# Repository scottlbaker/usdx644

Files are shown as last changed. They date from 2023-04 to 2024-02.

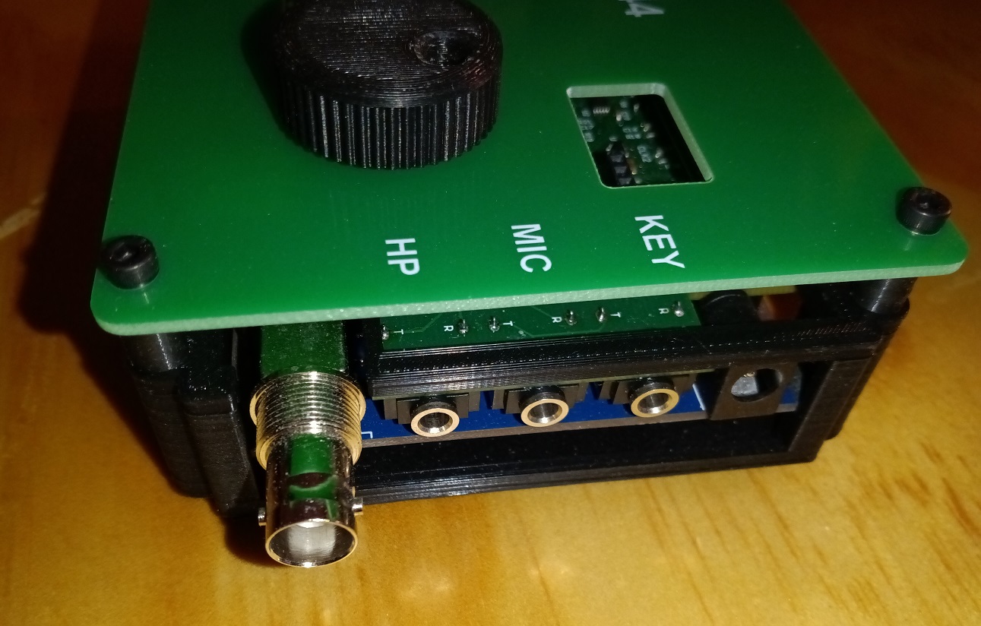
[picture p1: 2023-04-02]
hardware/pics/side_view.jpg

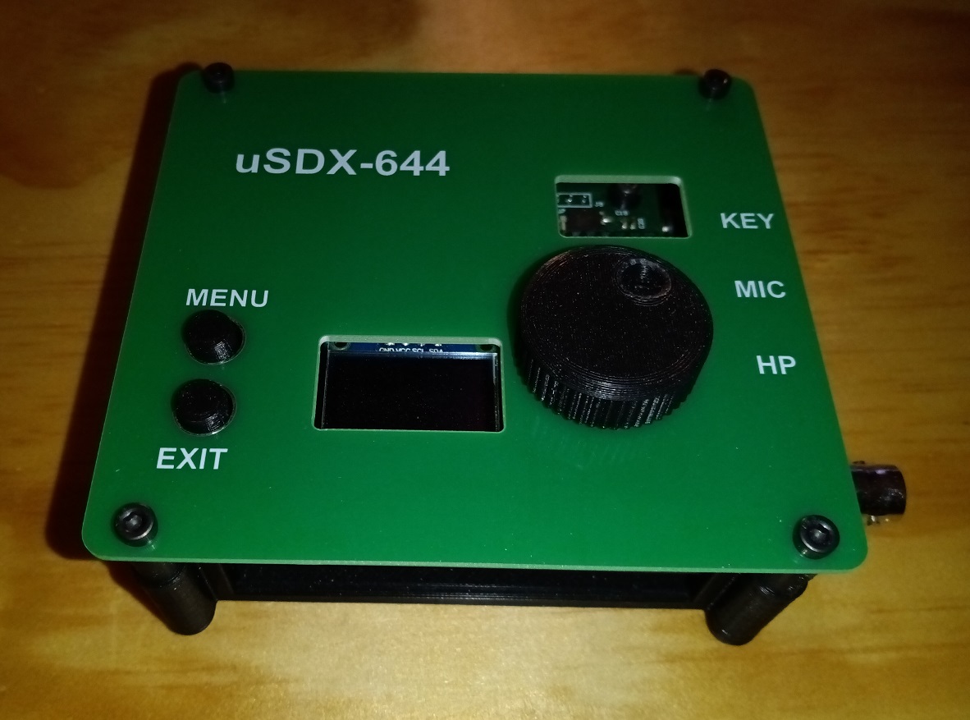
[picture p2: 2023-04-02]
hardware/pics/top_view.jpg

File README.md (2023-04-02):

## Summary

This SDR radio project was inspired by the uSDX project by Guido PE1NNZ.
The processor used is the Atmega644 processor which has more RAM and Flash memory
than the Atmega328 used in the uSDX project.

## Description

A single board SDR radio that is electrically and mechanically compaible with
an 8-band Chinese uSDX clone RF board.

## Contributors

* Scott L Baker

## License

See the **LICENSE** file in this repository

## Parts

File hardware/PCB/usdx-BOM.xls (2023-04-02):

Designator | Comment | Footprint | Quantity | Part Number
C1,C5,C6,C10,C11,C14,C15,C17,C19,C22,C25,C26,C27,C28,C29 | .1uF | 3-0603 | 15 | C113803
C2,C3,C7,C8 | .47uF | 3-0603 | 4 | C1623
C4,C9 | 1000pF | 3-0603 | 2 | C77026
C12,C13,C20,C21,C30,C31,C33 | 10uF | 3-0603 | 7 | C344022
C16,C23,C24 | .01uF | 3-0603 | 3 | C76710
C18,C32 | 1uF | 3-0603 | 2 | C5673
D1 | LED1 | 3-0603 | 1 | C72044
L1 | 100uH | 6-0805 | 1 | C223258
L2 | 3.3uH | 8-1008 | 1 | C250218
Q1 | CJ2302 | SOT23 | 1 | C8548
R1,R2,R3,R4,R17,R19,R30 | 1k | 3-0603 | 7 | C14676
R5,R6,R12,R13,R31 | 100 | 3-0603 | 5 | C22775
R7,R8,R9,R11,R14,R16,R20,R21,R24,R25,R26,R27,R28,R29,R32 | 10k | 3-0603 | 15 | C167144
R10,R15 | 82k | 3-0603 | 2 | C23254
R18 | 50 | 3-0603 | 1 | C23185
R22 | 4.7k | 3-0603 | 1 | C99782
R23 | 3.3k | 3-0603 | 1 | C22978
U2 | Si5351A | MSOP-10 | 1 | C1509083
U3 | LM4562 | SOIC-8 | 1 | C57367
U4 | FST3253 | TSSOP-16 | 1 | C424399
U5 | TLV702 | SOT-23-5 | 1 | C84119
U6,U8 | 74LVC1G08 | SOT23-5 | 2 | C434068
U7 | LM117-DPAK | TO252-3 | 1 | C129951

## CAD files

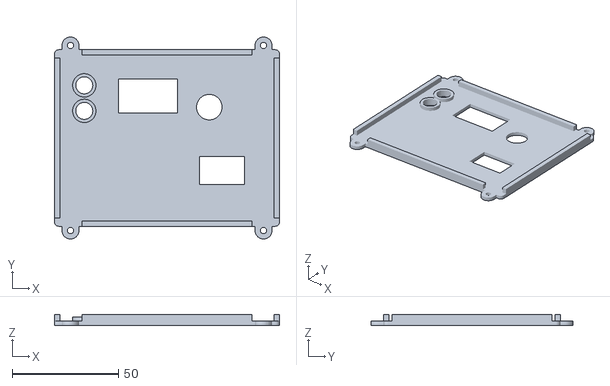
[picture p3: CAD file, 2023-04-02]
hardware/case/top.stl
105.8 x 95.0 x 5.00

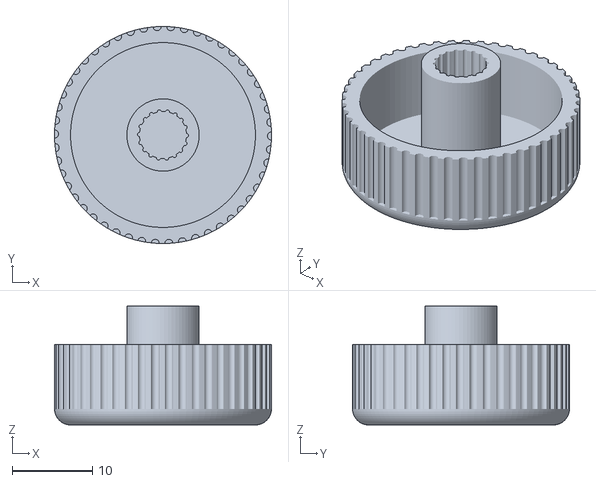
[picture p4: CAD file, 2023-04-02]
hardware/case/knob.stl
27.0 x 27.0 x 14.8

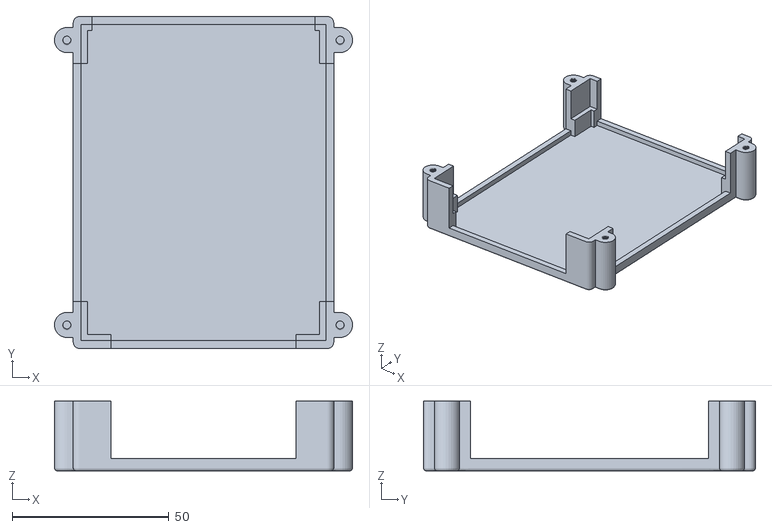
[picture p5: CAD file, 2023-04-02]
hardware/case/base.stl
95.0 x 105.8 x 22.2

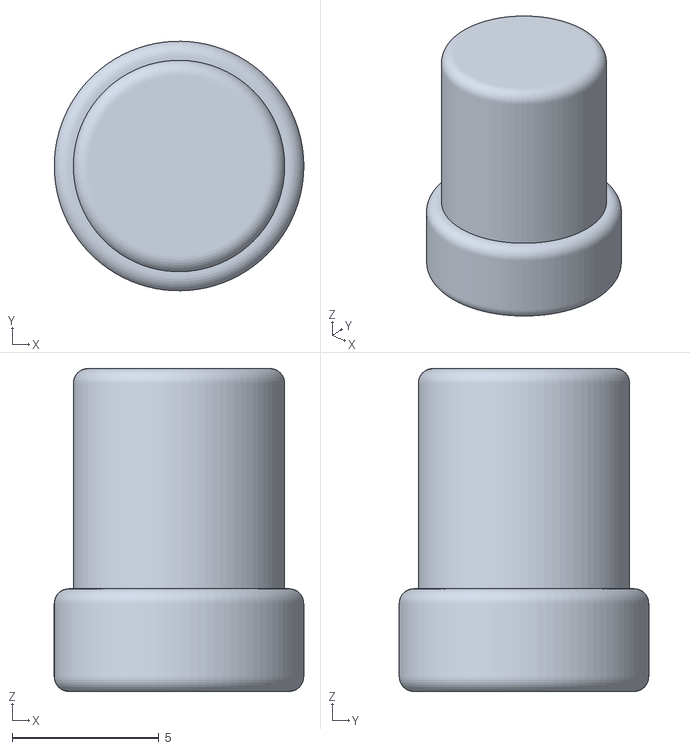
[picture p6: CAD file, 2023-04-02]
hardware/case/button.stl
8.50 x 8.50 x 11.0

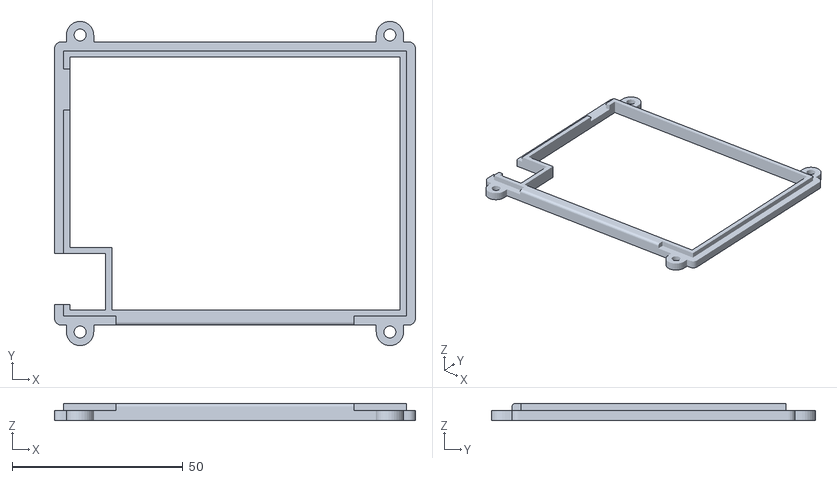
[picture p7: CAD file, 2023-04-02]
hardware/case/gasket.stl
105.8 x 95.0 x 5.00

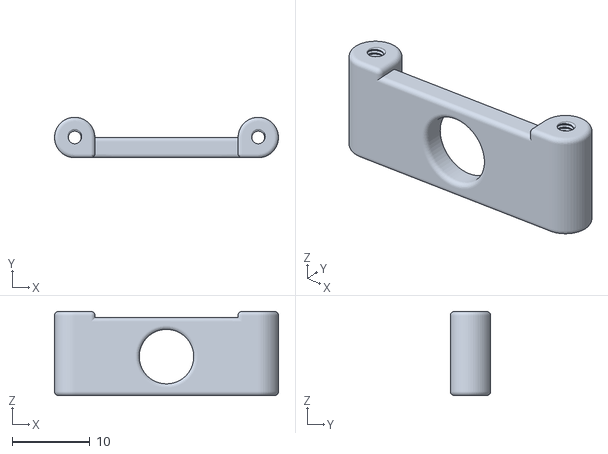
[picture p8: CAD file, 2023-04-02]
hardware/case/lcd.stl
28.8 x 5.20 x 10.8

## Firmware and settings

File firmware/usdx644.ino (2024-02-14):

// ============================================================================
//
// usdx644.ino :: An SSB/CW capable QRP transceiver
//
// (c) Scott Baker KJ7NLA
//
// This project was inspired by the uSDX project by Guido PE1NNZ
// which used the Atmega328 processor. This project uses the Atmega644
// processor which has more RAM and Flash memory
//
// Libraries
// ---------
// wire.h         - Arduino I2C lib
// wdt.h          - Arduino watchdog timer lib
// EEPROMex.h     - eeprom read/write lib
// font.h         - an OLED font that I created
//
// Arduino IDE settings
// --------------------
// board: Atmega644 (MightyCore)
// clock: external 16MHz
// BOD: BOD 2.7V
// eeprom: eeprom retained
// variant: 644P 644PA
// pinout: standard
// bootloader: no bootloader
// programmer: AVRISP mkII (MightyCore)
//
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
// ============================================================================

#define VERSION   "1.00X"               // firmware version
#define DATE      "Jan 14 2024"         // firmware release date

// Arduino Pins

#define QSDQ      PIN_PA0     // Q
#define QSDI      PIN_PA1     // I
#define MIC       PIN_PA2     // microphone
#define XP3       PIN_PA3     // extra pin (not used)
#define XP2       PIN_PA4     // extra pin (not used)
#define VBAT      PIN_PA5     // battery voltage
#define VFWD      PIN_PA6     // SWR fwd voltage
#define VREV      PIN_PA7     // SWR rev voltage

#define BLINKY    PIN_PB0     // diag LED
#define XP4       PIN_PB1     // extra pin (not used)
#define SDA0      PIN_PB2     // I2C bus #0 (si5351)
#define SCL0      PIN_PB3     // I2C bus #0 (si5351)
#define RXEN      PIN_PB4     // Receive control
#define MOSI      PIN_PB5     // SPI programming pin
#define MISO      PIN_PB6     // SPI programming pin
#define SCK       PIN_PB7     // SPI programming pin

#define SCL1      PIN_PC0     // I2C bus #1 (OLED)
#define SDA1      PIN_PC1     // I2C bus #1 (OLED)
#define UI2       PIN_PC2     // user button (exit)
#define UI1       PIN_PC3     // user button (menu)
#define UI3       PIN_PC4     // user button (encoder)
#define ROTA      PIN_PC5     // rotary encoder A
#define ROTB      PIN_PC6     // rotary encoder B
#define XPTT      PIN_PC7     // external amp control

#define RXD       PIN_PD0     // serial port Rx
#define TXD       PIN_PD1     // serial port Tx
#define CSS       PIN_PD2     // SPI select
#define DIT       PIN_PD3     // dit/ptt
#define PTT       PIN_PD3     // dit/ptt
#define TXPWM     PIN_PD4     // transmit PWM
#define SIDETONE  PIN_PD5     // sidetone
#define DAH       PIN_PD6     // dah
#define XP1       PIN_PD7     // extra pin (not used)

// uncomment to enable
//#define CAT             1   // CAT control
//#define CAT_EXT         1   // CAT extensions
//#define CAT_STREAMING   1   // CAT streaming
//#define LPF_NOLATCH     1   // non-latching relay support
//#define QUAD            1   // improve tx quality?
//#define SWR_METER       1   // SWR meter support

#define DEBUG1            0   // set to 1 for debug
#define DEBUG2            0   // set to 1 for debug

// ic2 addresses
#define SI5351_ADDR   0x60    // si5351
#define IOEXP16_ADDR  0x20    // for band select

// generic
#define OFF     0
#define ON      1
#define NO      0
#define YES     1
#define LAST    1
#define DOWN    0
#define UP      1
#define NONE    0
#define NOSHOW  0
#define SHOW    1
#define NOTX    1

// msec delay times
#define DEBOUNCE     20
#define ONE_SECOND   1000
#define TWO_SECONDS  2000

#define TIC   0
#define TOC   1

// used by decoder
#define DITX  0
#define DAHX  1

// used by setCursor
#define NOSCALE  0
#define SCALE    1

// CW decoder modes
#define XMIT  1
#define RECV  2
#define XTRA  3

// OLED display rows
#define ROW1  0
#define ROW2  1
#define ROW3  2
#define ROW4  3

// OLED display columns
#define STEPCOL   2
#define TWPMCOL   7
#define RWPMCOL  13
#define DBMCOL   12
#define SVALCOL  13
#define RMODECOL 13

// OLED display columns
#define MAXCOL  15

// agc settings
#define FAST  1
#define SLOW  2

// S-meter modes
#define DBM        1
#define SVAL       2
#define RXWPM      3

// SWR-meter modes
#define WATTS      1
#define VOLTS      2

// keyer modes
#define STRAIGHT   0   // straight key
#define IAMBIC_A   1   // Iambic A
#define IAMBIC_B   2   // Iambic B

// vfo settings
#define VFOA  0
#define VFOB  1

// SSB filters
#define FULL       0   // no bandwidth filtering
#define BW3000     1   // 3000Hz low-pass filter
#define BW2400     2   // 2400Hz low-pass filter
#define BW1800     3   // 1800Hz low-pass filter

// CW filters
#define BW500      1   // 500Hz band-pass filter
#define BW250      2   // 250Hz band-pass filter
#define BW100      3   // 100Hz band-pass filter
#define BW50       4   //  50Hz band-pass filter

// supported bands
#define B10M       0   // 10M band
#define B15M       1   // 15M band
#define B17M       2   // 17M band
#define B20M       3   // 20M band
#define B30M       4   // 30M band
#define B40M       5   // 40M band
#define B60M       6   // 60M band
#define B80M       7   // 80M band

// radio modes
#define  LSB    0
#define  USB    1
#define  CW     2
#define  FM     3
#define  AM     4

// CW decoder modes
#define  CWRX   1
#define  CWTX   2
#define  RXTX   3

// tuning step sizes
#define STEP_1M      0
#define STEP_100k    1
#define STEP_10k     2
#define STEP_1k      3
#define STEP_100     4
#define STEP_10      5
#define STEP_1       6

// menu variables
uint8_t volume     = 11;
uint8_t tonevol    = 15;
uint8_t radiomode  = USB;
uint8_t bwfilter   = FULL;
uint8_t cwfilter   = FULL;
uint8_t bandsel    = B20M;
uint8_t stepsize   = STEP_1k;
uint8_t vfosel     = VFOA;
uint8_t ritmode    = OFF;
uint8_t smeter     = RXWPM;
uint8_t swrmeter   = OFF;
uint8_t vox        = OFF;
uint8_t voxlevel   = 4;
uint8_t agc        = SLOW;
uint8_t nrlevel    = 2;
uint8_t attmic     = 0;    // mic attenuation
uint8_t attrx      = 0;    // Rx  attenuation
uint8_t att2       = 2;    // shift data to avoid overflow
uint8_t drive      = 4;
uint8_t txdelay    = 10;
uint8_t cwdec      = CWRX;
uint8_t semiqsk    = OFF;
uint8_t keyermode  = IAMBIC_A;
uint8_t keyerspeed = 25;
uint8_t keyswap    = OFF;
uint8_t practice   = ON;   // practice mode (no Tx)
uint8_t pwm_min    = 0;    // Tx PWM tuning
uint8_t pwm_max    = 128;  // Tx PWM tuning
uint8_t iqphase    = 90;
uint8_t notused    = 0;

uint8_t ditkey = DIT;
uint8_t dahkey = DAH;
uint8_t quad = 0;
uint8_t tx  = 0;
uint8_t acc_init = 0;
uint8_t skip_dsp = NO;
uint8_t cwdec_save = CWRX;
uint8_t practice_save = ON;
uint32_t t0;

// for display blank/timeout
#define ONE_MINUTE 60000
uint8_t display  = ON;
uint8_t xtimeout = 5;         // blank after 5 minutes
uint8_t xtimer   = 0;
uint32_t xdt;

uint32_t fxtal   = 27006000;  // si5351 xtal cal frequency

#if (ARDUINO < 10810)
   #error "Arduino IDE 1.8.10 or newer is required"
#endif
#if !(defined(ARDUINO_ARCH_AVR))
   #error "Unsupported architecture in Arduino IDE"
#endif
#if (F_CPU != 16000000)
   #error "Arduino IDE must specify 16MHz clock"
#endif

#undef  F_CPU
#define F_CPU 20007000  // actual frequency of 20MHz crystal
#define F_MCU 20000000  // 20MHz crystal

#include <avr/sleep.h>
#include <avr/wdt.h>
#include <EEPROMex.h>
#include "./include/font.h"
#include "./include/user.h"

// prototype defs
int8_t menuAction(uint8_t id);
void goertzel(uint8_t show);
void goto_rx(uint8_t show);
void goto_tx(uint8_t show, uint8_t notx);
void run_diags();
void saveAll();

inline void vox_process(uint8_t trigger);
inline int16_t arctan3(int16_t q, int16_t i);
inline int16_t ssb(int16_t in);
inline void minsky_init();
inline void process_minsky();
inline void insertchar();
inline void spinchar();
inline void gbuffer(int16_t ac);
inline void rxcw_decode(uint8_t show);
inline int16_t process_agc_fast(int16_t in);
inline int16_t process_agc(int16_t in);
inline int16_t process_nr(int16_t ac);
inline int16_t iirfilter(int16_t ac);
inline int16_t _arctan3(int16_t q, int16_t i);
inline int16_t slow_dsp(int16_t ac);
inline int16_t sdr_rx_common_q();
inline int16_t sdr_rx_common_i();

// button definitions
#define EXIT       0x10  // exit
#define MENU       0x20  // menu
#define ENCO       0x40  // encoder

// button events
#define CLICK      0x01  // click
#define LONG       0x02  // long press
#define DLP        0x04  // double-long press
#define TLP        0x08  // triple-long press

// button times (ms)
#define MS_LONG     300  // long
#define MS_DLP      600  // double-long
#define MS_TLP     1200  // triple-long

// menu IDs
enum menu_t {
  VOLUME, TONEVOL, RADIOMODE, BWFILTER, CWFILTER,
  NRLEVEL, BAND, STEP, PRACTICE,
  CWDEC, KEYERMODE, KEYERWPM, KEYSWAP, SEMIQSK,
  CWMSG1, CWMSG2, CWMSG3, CWMSG4, CWMSG5, CWMSG6,
  VFOSEL, SMETER, SWRMETER, VOX, VOXLEVEL, AGC, 
  ATTMIC, ATTRX, ATT2,
  DRIVE, TXDELAY, PWM_MIN, PWM_MAX, IQPHASE, REFCAL,
  CALLSIGN, NAME, ANT, RIG, PWR, QTH, FREQMEM,
  DIAG, SAVE, RIT, CWCAL, BATT, SWVER, SHDN,
  BLANK, N_PARAMS };

// user button macros
#define EXIT_PRESSED  !digitalRead(UI1)
#define MENU_PRESSED  !digitalRead(UI2)
#define ENCO_PRESSED  !digitalRead(UI3)
#define BUTTON_PRESSED (EXIT_PRESSED||MENU_PRESSED||ENCO_PRESSED)

// morse paddle macros
#define PTT_PRESSED  !digitalRead(PTT)
#define DIT_PRESSED  !digitalRead(ditkey)
#define DAH_PRESSED  !digitalRead(dahkey)
#define DIT_OR_DAH   (DIT_PRESSED || DAH_PRESSED)

// menumode definitions
#define NOT_IN_MENU   0
#define SELECT_MENU   1
#define SELECT_VALUE  2
#define EDIT_STRING   3

uint8_t menumode = NOT_IN_MENU;  // menu state variable
int8_t  menu     = VOLUME;       // currently selected menu item

#ifdef CAT_EXT
uint8_t cat_key = 0;
// reads pin or (via CAT) artificially overriden pins
uint8_t _digitalRead(uint8_t pin) {
  serialEvent();  // allows CAT update
  if (cat_key) {
    switch (pin) {
      case UI1:
        return (~cat_key&0x01);
      case UI2:
        return (~cat_key&0x02);
      case UI3:
        return (~cat_key&0x04);
      case DIT:
        return (~cat_key&0x10);
      case DAH:
        return (~cat_key&0x20);
      default:
        return (0);
    }
  }
  return digitalRead(pin);
}
#else
#define _digitalRead(x) digitalRead(x)
#endif // CAT_EXT

// keyerinfo bit definitions
#define DIT_REG     0x01     // dit pressed
#define DAH_REG     0x02     // dah pressed
#define KEY_REG     0x03     // dit or dah pressed
#define WAS_DIT     0x04     // last key was dit
#define BOTH_REG    0x08     // both dit/dah pressed

// keyer state machine
#define KEY_IDLE    0
#define CHK_KEY     1
#define KEY_WAIT    2
#define IDD_WAIT    3
#define LTR_GAP     4
#define WORD_GAP    5

uint8_t  keyerstate = KEY_IDLE;
uint8_t  keyerinfo  = 0;

uint16_t dittime;     // dit timing
uint16_t dahtime;     // dah timing
uint16_t lettergap;   // letter-gap timing
uint16_t wordgap;     // word-gap   timing

#define GOTKEY  (keyerinfo & KEY_REG)
#define NOKEY   !GOTKEY
#define GOTBOTH  GOTKEY == KEY_REG
#define NOTBOTH  GOTKEY != KEY_REG

// interruptable delay
void wait_ms(uint16_t dly) {
  uint32_t curTime = millis();
  uint32_t endTime = curTime + dly;
  while(curTime < endTime) {
    delayMicroseconds(100);
    wdt_reset();
    curTime = millis();
  }
}

// read and debounce paddles
void read_paddles() {
  uint8_t ditv1 = DIT_PRESSED;
  uint8_t dahv1 = DAH_PRESSED;
  if (ditv1 || dahv1) {
    wait_ms(1);
    uint8_t ditv2 = DIT_PRESSED;
    uint8_t dahv2 = DAH_PRESSED;
    if (ditv1 && ditv2) {
      keyerinfo |= DIT_REG;
    }
    if (dahv1 && dahv2) {
      keyerinfo |= DAH_REG;
    }
    if (GOTBOTH) keyerinfo |= BOTH_REG;
  }
}

// I2C bus used by OLED
class I2C1 {
public:

  I2C1() {
    TWBR = 12;  // set SCL delay
    TWSR = 0;   // set prescaler to 1
    TWCR = (1<<TWEN);  // enable
  }

  // start of transmission
  void start(uint8_t address) {
    // send start condition
    TWCR = (1<<TWINT) | (1<<TWSTA) | (1<<TWEN);
    while (!(TWCR & (1<<TWINT)));
    // send address
    TWDR = address<<1;
    TWCR = (1<<TWINT) | (1<<TWEN);
    while (!(TWCR & (1<<TWINT)));
  }

  // write data
  void write(uint8_t data) {
    TWDR = data;
    TWCR = (1<<TWINT) | (1<<TWEN);
    while (!(TWCR & (1<<TWINT)));
  }

  // end of transaction
  void stop() {
    TWCR = (1<<TWINT) | (1<<TWSTO) | (1<<TWEN);
    while (TWCR & (1<<TWSTO));
  }
};

I2C1 i2c1;

// SSD1306 OLED initialization sequence
const uint8_t oled_init_sequence [] = {
  0xD5, 0x80,   // set display clock divide ratio
  0xA8, 0x3F,   // Set multiplex ratio to 1:64
  0xD3, 0x00,   // set display offset = 0
  0x40,         // set display start line address
  0x8D, 0x14,   // set charge pump, internal VCC
  0x20, 0x02,   // set memory addressing
  0xA4,         // output RAM to display
  0xA1,         // set segment re-map
  0xC8,         // set COM output scan direction
  0xDA, 0x12,   // Set com pins hardware configuration
  0x81, 0x80,   // set contrast control register
  0xDB, 0x40,   // set vcomh
  0xD9, 0xF1,   // 0xF1=brighter
  0xB0,         // set page address (0-7)
  0xA6,         // set display mode to normal
  0xAF,         // display ON
};
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
void loop() {
  uint8_t event;                // click long press
  uint8_t button;               // which button

  // CW decoder active during RX
  if ((menumode == NOT_IN_MENU) && (radiomode == CW) &&
     ((cwdec == CWRX) || (cwdec == RXTX)) &&
       gcdone && gdbrdy && !tx && !semiqsk_timeout) rxcw_decode();

  // S-meter calculations
  if ((menumode == NOT_IN_MENU) && !semiqsk_timeout && !vox_tx) calc_smeter();

  // select straight key or iambic keyer
  if ((menumode == NOT_IN_MENU) && (radiomode == CW)) {
    if (keyermode == STRAIGHT) straight_key();
    else iambic_keyer();
  }

  // a long press of DAH will switch to CW mode
  if ((menumode == NOT_IN_MENU) && (radiomode != CW) && DAH_PRESSED) {
    t0 = millis();
    while (DAH_PRESSED) {
      if ((millis() - t0) > 700) {
        radiomode = CW;
        vfomode[vfosel] = radiomode;
        si5351.iqmsa = 0;
        update_freq = YES;
        break;
      }
      wait_ms(1);
      wdt_reset();
    }
  }

  // handle ptt button when in ssb modes
  if ((radiomode < CW) && PTT_PRESSED) {
    goto_tx(SHOW, OFF);
    while (PTT_PRESSED) delay(DEBOUNCE);
    goto_rx(SHOW);
  }

  // play side tone when in tone volume menu
  if ((menumode == SELECT_VALUE) && (menu == TONEVOL)) check_ditdah();

  // check for semi-qsk timeout
  if (semiqsk_timeout && (millis() > semiqsk_timeout))
    goto_rx(SHOW);

  // check for encoder turned while UI locked
  if (ui_locked && encoder_ui) {
    show_locked();
    delay(DEBOUNCE);
    encoder_ui = 0;
    encoder_val = 0;
    event = NONE;
    goto end_of_loop;   // skip all UI processing
  }

  // check for encoder or button while screen blanked
  if ((display == OFF) && (encoder_val || BUTTON_PRESSED)) {
    display = ON;
    oled.onDisplay();
    wait4release();
    encoder_val = 0;
    event = NONE;
    goto end_of_loop;   // skip all UI processing
  }

  if (BUTTON_PRESSED) {

    if (ENCO_PRESSED) button = ENCO;
    if (MENU_PRESSED) button = MENU;
    if (EXIT_PRESSED) button = EXIT;

    reset_xdt();  // reset display timeout

    if (!(event & LONG)) {
      event = CLICK;
      t0 = millis();
      while (BUTTON_PRESSED) {
        if (EXIT_PRESSED) button |= EXIT;
        if (MENU_PRESSED) button |= MENU;
        if (ENCO_PRESSED) button |= ENCO;
        // until released or long press
        if ((millis() - t0) > MS_LONG) { event = LONG; break; }
        wait_ms(1);
        wdt_reset();
      }

#ifdef CAT_EXT
      if (cat_key) {
        if (cat_key&0x01) button = EXIT;
        if (cat_key&0x02) button = MENU;
        if (cat_key&0x04) button = ENCO;
      }
#endif // CAT_EXT

      event |= button;  // add button info
    }

    // enforce the UI lock
    if (ui_locked) {
      if (EXIT_PRESSED) {
        t0 = millis();
        while (EXIT_PRESSED) {
          // check for triple-long press
          if ((millis() - t0) > MS_TLP) { event = TLP; break; }
          wait_ms(1);
          wdt_reset();
        }
      }
      if (event == TLP) {
        // a triple-long press will unlock the UI
        ui_locked = NO;
        show_unlock();
      } else {
        // ignore other button press while UI locked
        show_locked();
        wait4release();
      }
      event = NONE;
      goto end_of_loop;   // skip all UI processing
    }

    switch (event) {
      case EXIT|MENU|LONG:
        // a long press of both exit and menu will lock the UI
        if (menumode == NOT_IN_MENU) {
          ui_locked = YES;
          show_lock();
        }
        break;
      case MENU|CLICK:
        if ((menu >= CWMSG1) && (menu <= CWMSG6) &&
          (menumode == SELECT_MENU) && (radiomode == CW)) {
          // send a CW message
          send_cwmsg(menu-CWMSG1);
        }
        else switch (menumode) {
          case NOT_IN_MENU:
            menumode = SELECT_MENU;      // enter menu mode
            menuAction(menu);
            break;
          case SELECT_MENU:
            if ((menu >= CALLSIGN) && (menu <= QTH)) {
              menumode = EDIT_STRING;    // enter edit string mode
              oled.clrLine(ROW2);
              show_edit();
              get_spinpos(editstr[editpos]);
              show_cursor(ON);
            } else {
              menumode = SELECT_VALUE;   // enter value selection
              menuAction(menu);
            }
            break;
          case SELECT_VALUE:
            menumode = SELECT_MENU;      // back to menu mode
            menuAction(menu);
            break;
          case EDIT_STRING:
            editpos++;
            get_spinpos(editstr[editpos]);
            show_cursor(ON);
            break;
          default:
            break;
        }
        break;
      case MENU|LONG:
        switch (menumode) {
          case NOT_IN_MENU:
            // a long press of menu for keyer speed
            menumode = SELECT_VALUE;
            menu = KEYERWPM;
            menuAction(menu);
            t0 = millis();
            while (MENU_PRESSED) {
              // check for double-long press
              if ((millis() - t0) > MS_DLP) { event = DLP; break; }
              wait_ms(1);
              wdt_reset();
            }
            if (event == DLP) {
              // a double-long press for band selection
              menu = BAND;
              menuAction(menu);
            }
            break;
          case SELECT_MENU:
          case SELECT_VALUE:
          case EDIT_STRING:
          default:
            break;
        }
        break;
      case EXIT|CLICK:
        switch (menumode) {
          case NOT_IN_MENU:
            if (ritmode) {
              ritmode = OFF;  // disable RIT
              ritval = 0;
              update_freq = YES;
              break;
            }
            radiomode++;
            if (radiomode > CW) radiomode = LSB;  // only LSB, USB, CW
            vfomode[vfosel] = radiomode;
            si5351.iqmsa = 0;
            oled.clrR23();
            update_freq = YES;
            break;
          case SELECT_MENU:
          case SELECT_VALUE:
            menumode = NOT_IN_MENU;    // back to main screen
            main_screen();
            if (menu == KEYERWPM) beep_cw("V");  // acknowledge change
            if (menu == REFCAL) EEPROM.updateLong(CALFREQ_ADDR, fxtal);
            break;
          case EDIT_STRING:
            menumode = SELECT_MENU;    // back to menu mode
            show_cursor(OFF);
            menuAction(menu);
            break;
          default:
            break;
        }
        break;
      case EXIT|LONG:
        if (menumode == NOT_IN_MENU) {
          // a long press of exit will open the frequency list
          menumode = SELECT_MENU;
          menu = FREQMEM;
          menuAction(menu);
          t0 = millis();
          while (EXIT_PRESSED) {
            // check for double-long press
            if ((millis() - t0) > MS_DLP) { event = DLP; break; }
            wait_ms(1);
            wdt_reset();
          }
          if (event == DLP) {
            while (EXIT_PRESSED) {
              // check for triple-long press
              if ((millis() - t0) > MS_TLP) { event = TLP; break; }
              wait_ms(1);
              wdt_reset();
            }
          }
          switch (event) {
            case DLP:
              // a double-long press will open the RIT menu
              menu = RIT;
              menuAction(menu);
              break;
            case TLP:
              // a triple-long press will blank the screen
              menumode = NOT_IN_MENU; // back to main screen
              main_screen();
              display = OFF;
              oled.noDisplay();
              wait4release();
            default:
              break;
          }
        }
        break;
      case ENCO|CLICK:
        switch (menumode) {
          case NOT_IN_MENU:
            stepsize_change();
            break;
          case SELECT_VALUE:
            if (menu == REFCAL) ref_stepsize_change();
            break;
          case EDIT_STRING:
            insertchar();
            break;
          case SELECT_MENU:
          default:
            break;
        }
        break;
      case ENCO|LONG:
        switch (menumode) {
          case NOT_IN_MENU:
            // a long press of encoder for volume control
            menumode = SELECT_VALUE;
            menu = VOLUME;
            menuAction(menu);
            t0 = millis();
            while (ENCO_PRESSED) {
              // check for double-long press
              if ((millis() - t0) > MS_DLP) { event = DLP; break; }
              wait_ms(1);
              wdt_reset();
            }
            if (event == DLP) {
              // a double-long press for tone volume
              menu = TONEVOL;
              menuAction(menu);
              t0 = millis();
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
